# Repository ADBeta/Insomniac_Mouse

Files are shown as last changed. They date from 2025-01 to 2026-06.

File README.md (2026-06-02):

# Insomniac Mouse MkII
USB HID Mouse Device using a 10¢ Microcontroller.  
Moves randomly to keep PCs awake; make games harder to play; annoy co-workers 
and friends; or to give you a digital fishbowl to watch.  
Each board has jumpers to change the Mouse Behaviour, a lanyard loop,
and is designed with minimum cost and complexity.

Using [ch32v003fun](https://github.com/cnlohr/ch32v003fun) and 
[rv003usb](https://github.com/cnlohr/rv003usb) to create a Software Defined
HID Mouse - it then uses `Bresenham's Line Algorithm` to plot lines for the
mouse to move.

<div style="display: flex; align-items: center; gap: 10px;">
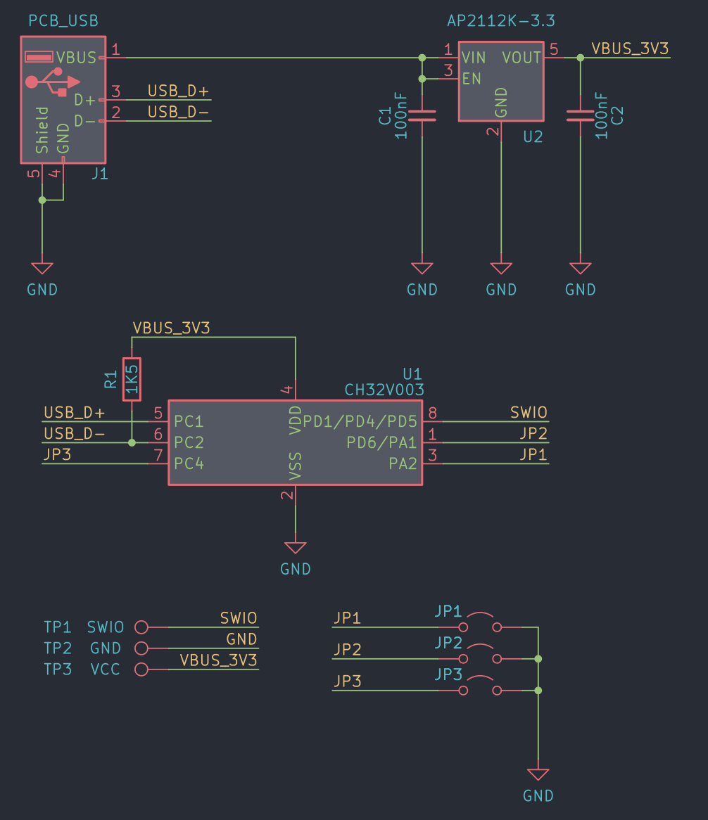
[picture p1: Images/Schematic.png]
Schematic
  <br>
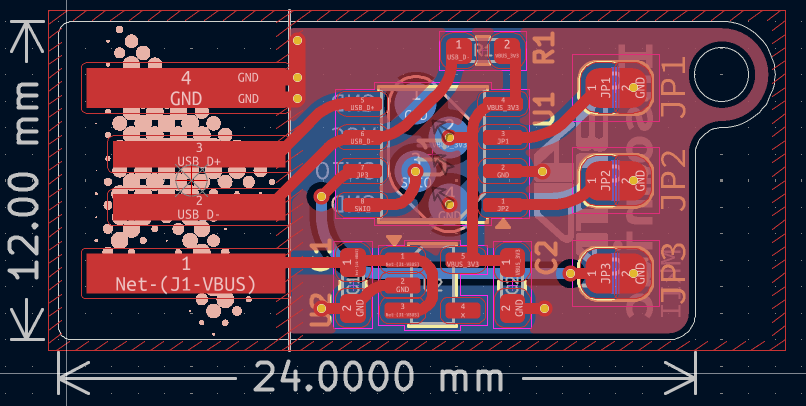
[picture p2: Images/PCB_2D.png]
PCB_2D
  <br>
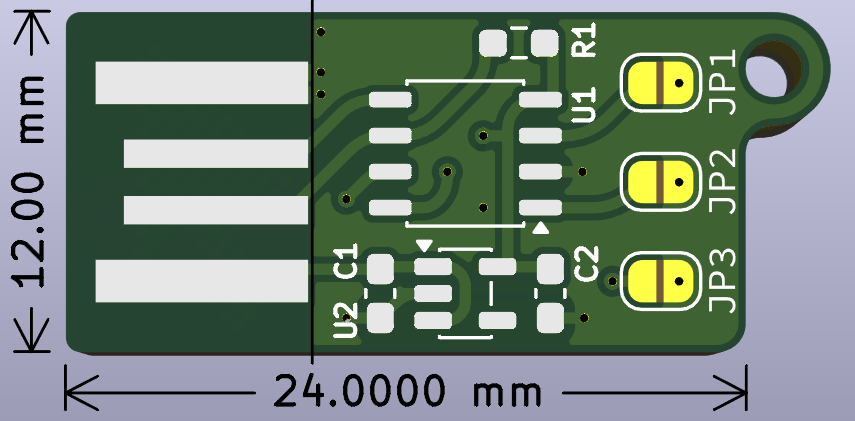
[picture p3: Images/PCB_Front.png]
PCB_Front
  
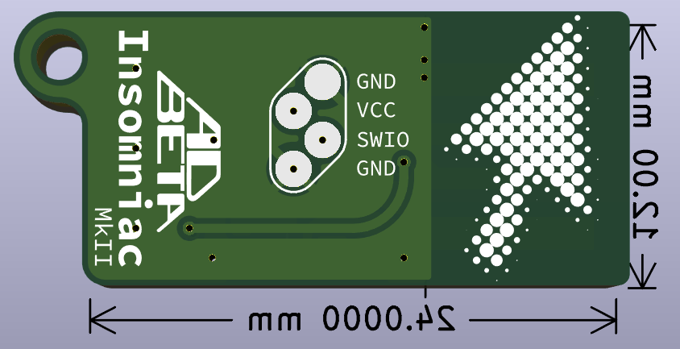
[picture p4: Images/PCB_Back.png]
PCB_Back
  
</div>

## Jumpers

| Mode | J1  | J2  | J3  | Description | Usecase |
|---|-----|-----|-----|---|---|
| Normal |  0  |  0  |  0  | ±125 Units Movement | Default balance of speed and distance |
| Hi-Res |  1  |  0  |  0  | ±250 Units Movement | Longer movement for Hi DPI Displays |
| Jitter |  0  |  1  |  0  | ±20 Units Movement | More chaotic movement. Good for messing with games |
| Stepped  |  1  |  1  |  0  | ±2 Unit Movement (Slower) | Slow mode for controllability while plugged in |
| Square |  0  |  0  |  1  | Lock movement to a square | Prevents the mouse from wandering too far |
| Unused |  1  |  0  |  1  | | |
| Unused |  0  |  1  |  1  | | |
| Unused |  1  |  1  |  1  | | |

## Uses
### Keeping PCs awake
Even if you disable Screensaver/Sleep mode, some PCs go to sleep anyway - 
this forces the machine to stay awake regardless.  
This is especially useful on Industial, Unmanaged and headless machines.

### Testing USB Ports
Due to the very low power consumption, small size, lanyard loop, USB 1.0
connection spec, and simple HID data, this is a perfect cheap USB Tester.

### Activity Monitor Spoofing
Because this moves the mouse like any other HID Mouse, it keeps users as
`"Online"` on Teams, Slack etc programs which monitor user activity.  
**WARNING This is not recommended, and any touble you get into for doing this
is your own fault.**

### Pranks / Game Challenges
Guaranteed to annoy your friends and make games **much** harder to play.  

### Creating Artwork
Hold down the mouse in an art package of your choice to create 
some.... interesting art.  
<div style="display: flex; align-items: center; gap: 10px;">
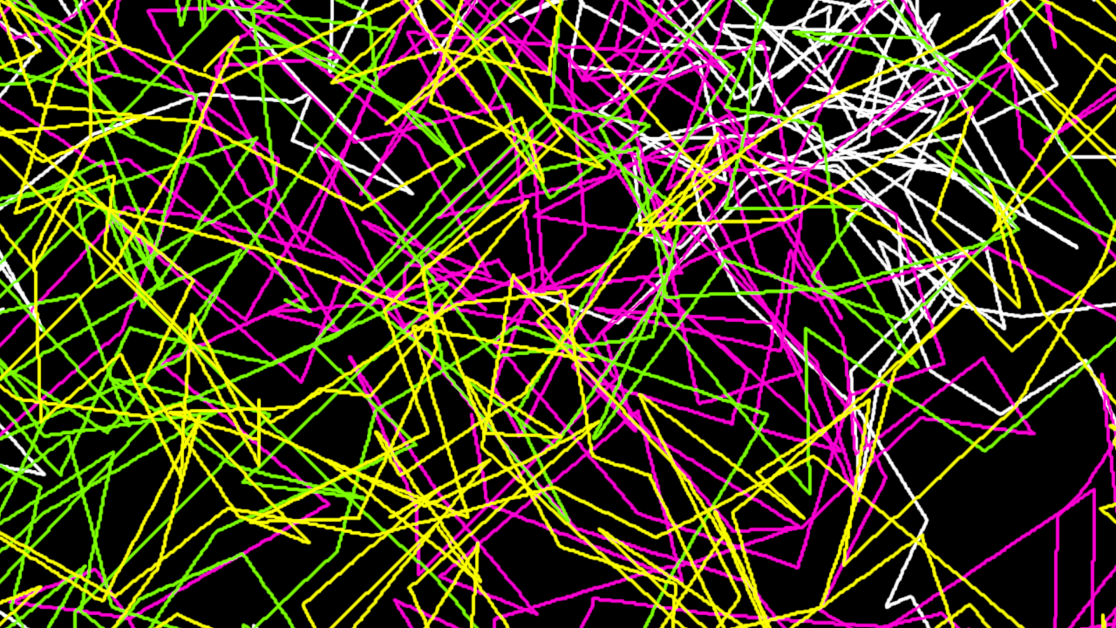
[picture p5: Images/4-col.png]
art 4 colour
  <br>
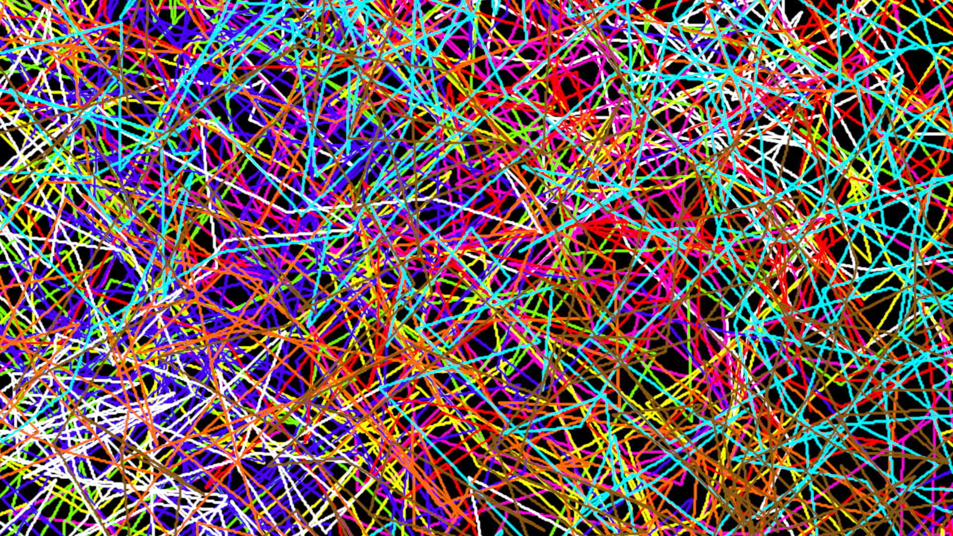
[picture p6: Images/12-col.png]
art 12 colour
  <br>
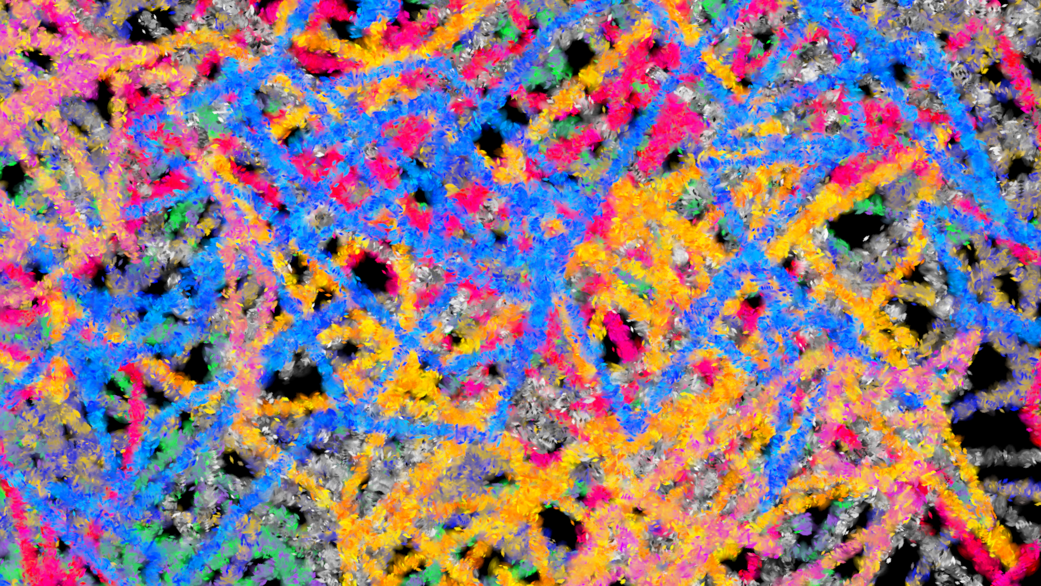
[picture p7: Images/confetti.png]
art confetti
  <br>
</div>

## PCB Specification
The overall thickness of the PCBs **MUST** be between 2.0mm and 2.4mm.  
`MkII` Offers more adaptability to get to this final thickness easily.
* Order `Insomniac_USB_Gerb` as a 2.0mm PCB
* Order `Insomniac_USB_Gerb` as a 1.6mm PCB and glue on a 0.4mm - 0.8mm Shim
* Order `Insomniac_USB_Gerb` and `Insomniac_Shim_Gerb` as 1.2mm or 1.0mm PCBs and glue together

## Partslist
```
U1    CH32V003J4M6       SOIC-8
U2    AP2112K-3.3        SOT-23-5
C1    100nF MLCC         0603
C2    100nF MLCC         0603
R1    1.5K Ohm           0603
```

## CHANGELOG
* V1.0.1 - Fixed a compatability issue with Windows
* V1.1.2 - Refactor functions and vairable names
* V1.2.0 - Added Diagonal Movement for USB HID Data, improves smoothness
* V1.3.2 - Changed Jumper Detection Method & added `JITTER` Mode
* V1.4.0 - Refined the code and added `CALM` Mode.
* V1.5.0 - Added USB Serial Number based on UUID of the MCU
* V2.0.0 - MkII PCB and minor bug fixes & refactor
* V2.1.0 - Added Square Limit Mode

## TODO

----
MIT License
Copyright (c) 2025-2026 ADBeta

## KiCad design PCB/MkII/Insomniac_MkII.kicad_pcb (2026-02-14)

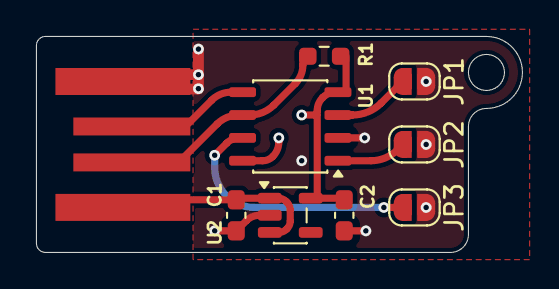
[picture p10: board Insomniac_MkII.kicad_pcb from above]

Board: 2 copper layers, 27.0 x 12.0 mm, 10 parts (1 on the bottom side), 9 nets.

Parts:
C1, C2: 100nF; C_0603_1608Metric_Pad1.08x0.95mm_HandSolder
J1: PCB_USB; PCB_USB_A
J2: CONN_PROG; Program_Conn
JP1: JP1; SolderJumper-2_P1.3mm_Open_RoundedPad1.0x1.5mm
JP2: JP2; SolderJumper-2_P1.3mm_Open_RoundedPad1.0x1.5mm
JP3: JP3; SolderJumper-2_P1.3mm_Open_RoundedPad1.0x1.5mm
R1: 1K5; R_0603_1608Metric_Pad0.98x0.95mm_HandSolder
U1: CH32V003JxMx; JEITA_SOIC-8_3.9x4.9mm_P1.27mm
U2: AP2112K-3.3; SOT-23-5

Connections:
/JP1: JP1.1 (A), U1.3 (PA2)
/JP2: JP2.1 (A), U1.1 (PD6/PA1)
/JP3: JP3.1 (A), U1.7 (PC4)
/SWIO: J2.3, U1.8 (PD1/PD4/PD5)
/USB_D+: J1.3 (D+), U1.5 (PC1)
/USB_D-: J1.2 (D-), R1.1, U1.6 (PC2)
/VBUS_3V3: C2.1, J2.2, R1.2, U1.4 (VDD), U2.5 (VOUT)
GND: C1.2, C2.2, J1.4 (GND), J2.1, J2.4, JP1.2 (B), JP2.2 (B), JP3.2 (B), U1.2 (VSS), U2.2 (GND)
unnamed: C1.1, J1.1 (VBUS), U2.1 (VIN), U2.3 (EN)

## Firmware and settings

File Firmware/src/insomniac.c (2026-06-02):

/******************************************************************************
* Insomiac Mouse Emulator
* Connects over USB as a generic HID Mouse, then moves continuously to keep
* PCs awake, or just to waste some time watching it dance!
* See the GitHub: https://github.com/ADBeta/Insomniac_Mouse
*
* Pinout:
* 	USB+   PC1
* 	USB-   PC2
* 	JP1    PA2
* 	JP2    PA1
* 	JP3    PC4
*
* ADBeta (c) 2025-2026    02 Jun 2026    Ver2.1.0
******************************************************************************/
#include "ch32v003fun.h"
#include "rv003usb.h"
#include "lib_rand.h"
#include "serial_uuid.h"

//#include <stdio.h>          // NOTE: Comment out when net debugging

/*** Macro Functions *********************************************************/
#define CLAMP(v, min, max)  ((v) < (min) ? (min) : ((v) > (max) ? (max) : (v)))


/*** Types and Definitions ***************************************************/
/// @brief A C-ordinate position struct, X/Y Data can be positive or negative
typedef struct {
	int16_t          x;
	int16_t          y;
} position_t;


/// @brief Remapping of a uint8_t to movement instruction, 2 nibbles
/// [Up    /   Down]  [Left  /  Right]
///  1100      0011    1100      0011
typedef uint8_t mouse_instr_t;
#define MOUSE_INSTR_U      0b11000000
#define MOUSE_INSTR_D      0b00110000
#define MOUSE_INSTR_L      0b00001100
#define MOUSE_INSTR_R      0b00000011


typedef enum {
	MI_BUFFER_OK             = 0,
	MI_BUFFER_NO_SPACE,             // No Space to append to buffer
	MI_BUFFER_NO_DATA               // No Data to read from the buffer
} mi_buffer_status_t;


// User Mode Selection from the Jumpers - Reads the jumpers in binary on boot
typedef enum {
	USER_MODE_NORMAL     = 0b000,
	USER_MODE_HI_RES     = 0b001,
	USER_MODE_JITTER     = 0b010,
	USER_MODE_STEPPED    = 0b011,
	USER_MODE_SQUARE     = 0b100
} user_mode_t;




/*** Globals *****************************************************************/
// Ring Buffer Variables
#define                 MI_BUFFER_SIZE   512
static mouse_instr_t    g_mi_buffer[MI_BUFFER_SIZE];
volatile uint32_t       g_mi_buffer_head = 0;
volatile uint32_t       g_mi_buffer_tail = 0;


// Buffer is ready for another movement flag.
// 0x00 Not Empty
// 0x01 Empty
volatile uint8_t        g_buffer_empty_flag = 0x00;


// User Settings Flags
static user_mode_t   g_user_mode     = USER_MODE_NORMAL;



/*** Forward Declarations ****************************************************/
/// @brief Efficient Implimentation of an integer abs() function
/// @param input x
/// @param output abs(x)
uint32_t int_abs(const int32_t x);


/// @brief Generates a random signed integer, limited to a maximum range
/// @param None
/// @return int16_t integer
int16_t int_rand(void);


/// @brief Mouse Instruction Ring Buffer Push (Puts data in the buffer)
/// @param Mouse Instruction
/// @return Mouse Instruction Status
mi_buffer_status_t mi_buffer_push(const mouse_instr_t inst);


/// @brief Mouse Instruction Ring Buffer Pop (Pulls off data from buffer)
/// @param Mouse Instruction Pointer
/// @return Mouse Instruction Status
mi_buffer_status_t mi_buffer_pop(mouse_instr_t *instr);


/// @brief Mouse Instruction Ring Buffer Peek (Reads value without incrimenting)
/// @param Mouse Instruction Pointer
/// @return Mouse Instruction Status
mi_buffer_status_t mi_buffer_peek(mouse_instr_t *instr);


/// @brief Mouse Instruction Ring Buffer Skip (Skip current buffer data)
/// @param None
/// @return Mouse Instruction Status
mi_buffer_status_t mi_buffer_skip(void);


/// @brief Plots movement to a given co-ordinate point. Appends the movement
/// data to the circuilar buffer to be dispatched to the USB Interrupt
/// @param postion_t endpoint to plot to. Contains X/Y data, can be positive
/// or negative
/// @return Mouse Inscription buffer status - if push fails
mi_buffer_status_t move_to_endpoint(const position_t endpoint);


/// @brief sets HID mouse bytes from an input Mouse Movement Instruction
/// @param buffer to modify
/// @param instruction to parse
/// @return None
void set_mouse_instr_bytes(uint8_t *buffer, mouse_instr_t instr);


/// @brief Tracks the absolute position of the pointer and limits it to a
/// given square
/// @param pos, pointer to the position to add, returns the modified position
/// @return None
void limit_endpoint_to_square(position_t *pos);



/*** Main ********************************************************************/
int main(void)
{
	/*** System Init ********************/
	// Grab two words from the near-top of RAM - Should be uninitialised noise
	uint32_t ram_val =   *((volatile uint32_t*)0x20000700) 
		               ^ *((volatile uint32_t*)0x200007AA);
	// Set the LFSR Seed to the RAM Value, provided it is not 0x00.. or 0xFF..
	// If this doesn't seed the default will be used
	if(ram_val != 0x00000000 && ram_val != 0xFFFFFFFF)
		seed(ram_val);


	SystemInit();


	// Set the USB Serial String to the UUID of the MCU
	set_usb_serial_uuid();


	/*** GPIO ***************************/
	// Enable the GPIO Channels
	RCC->APB2PCENR |= RCC_APB2Periph_GPIOA | RCC_APB2Periph_GPIOC;

	// Clear PA1 PA2 and PC4, set them to Push/Pull, then write PULLUP
	GPIOA->CFGLR &= ~((0x0000000F << 4) | (0x0000000F << 8));
	GPIOA->CFGLR |=  ((GPIO_CFGLR_IN_PUPD << 4) | (GPIO_CFGLR_IN_PUPD << 8));
	GPIOA->OUTDR |=  ((0x01 << 1) | (0x01 << 2));

	GPIOC->CFGLR &= ~(0x0000000F << 16);
	GPIOC->CFGLR |=  (GPIO_CFGLR_IN_PUPD << 16);
	GPIOC->OUTDR |=  (0x01 << 4);

	// Read the Jumpers to set the user_mode
	g_user_mode |= (!((GPIOA->INDR >> 2) & 1)) << 0;  // PA2
	g_user_mode |= (!((GPIOA->INDR >> 1) & 1)) << 1;  // PA1
	g_user_mode |= (!((GPIOC->INDR >> 4) & 1)) << 2;  // PC4


	/*** USB ****************************/
	// Ensures USB re-enumeration after bootloader or reset
	Delay_Ms(1); 
	usb_setup();


	while(1) 
	{
		// NOTE: Prints random values to evaluate random number algorithm
		//printf("%d\n", int_rand());

		// Wait for the flag that the buffer is empty
		if(g_buffer_empty_flag)
		{
			// Generate a random position then push the commands to move to it
			position_t rand_pos = {.x = int_rand(), .y = int_rand()};

			// Limit the Endpoints to a defined square if selected
			if(g_user_mode == USER_MODE_SQUARE)
				limit_endpoint_to_square(&rand_pos);
			
			// Move to the given endpoint
			move_to_endpoint(rand_pos);

			// Reset the empty flag, waits until it is done moving
			g_buffer_empty_flag = 0x00;			
		}


		// Add a delay for Calm mode to increase usability
		if(g_user_mode == USER_MODE_STEPPED)
			Delay_Ms(1000);

	} 
	// end of loop
	

	return 0;
}



/*** Functions ***************************************************************/
// rv003usb HID Function
void usb_handle_user_in_request( struct usb_endpoint * e, uint8_t * scratchpad, int endp, uint32_t sendtok, struct rv003usb_internal * ist )
{
	static mouse_instr_t crnt_mouse_instr;
	static mouse_instr_t next_mouse_instr;
	// Define an empty mouse bytes array
	uint8_t mouse_bytes[4] = {0x00, 0x00, 0x00, 0x00};

	// Handle the USB Mouse messages
	if(endp == 1)
	{
		// Get the current and next data chunks
		mi_buffer_status_t crnt_buffer_status = mi_buffer_pop(&crnt_mouse_instr);
		mi_buffer_status_t next_buffer_status = mi_buffer_peek(&next_mouse_instr);

		// If the current status is OK, set the data bytes
		if(crnt_buffer_status == MI_BUFFER_OK)
		{
			set_mouse_instr_bytes(mouse_bytes, crnt_mouse_instr);
		}

		// If it's empty, set the flag and leave the buffer unset
		else
		{
			g_buffer_empty_flag = 0x01;
		}


		// If the next instruction is valid, parse it (Allows for diagonal movement)
		if(next_buffer_status == MI_BUFFER_OK)
		{
			// If this instruction is LEFT or RIGHT, and the previous was UP or DOWN,
			// add this instruction to the data
			if((next_mouse_instr == MOUSE_INSTR_L || next_mouse_instr == MOUSE_INSTR_R)
			&& (crnt_mouse_instr == MOUSE_INSTR_U || crnt_mouse_instr == MOUSE_INSTR_D))
			{
				set_mouse_instr_bytes(mouse_bytes, next_mouse_instr);
				mi_buffer_skip();
			}

			// Likewise with UP and DOWN, append if last instruction was LEFT or RIGHT
			if((next_mouse_instr == MOUSE_INSTR_U || next_mouse_instr == MOUSE_INSTR_D)
			&& (crnt_mouse_instr == MOUSE_INSTR_L || crnt_mouse_instr == MOUSE_INSTR_R))
			{
				set_mouse_instr_bytes(mouse_bytes, next_mouse_instr);
				mi_buffer_skip();
			}
		}
		

		// Send the data to the USB Controller - Either 0x00's or has Delta data
		usb_send_data(mouse_bytes, 4, 0, sendtok);
	}
	else
	{
		// If it's a control transfer, empty it.
		usb_send_empty(sendtok);
	}
}


void set_mouse_instr_bytes(uint8_t buffer[], mouse_instr_t instr)
{
	// signed 8 bit ints for movement, using Unsigned representation
	// [1] is (0xFF)L  (0x01)R
	// [2] is (0xFF)U  (0x01)D
	switch(instr)
	{
		case MOUSE_INSTR_L:
			buffer[1] |= 0xFF;
			break;
		case MOUSE_INSTR_R:
			buffer[1] |= 0x01;
			break;

		case MOUSE_INSTR_U:
			buffer[2] |= 0xFF;
			break;
		case MOUSE_INSTR_D:
			buffer[2] |= 0x01;
			break;
	}
}


int16_t int_rand(void)
{
	int16_t rand_num;

	// NOTE: Generate a random number, bitmask it to get it within range
	// so the modulo operation isn't noticable slow.
	// Modulo by (Maximum + 1), then subtract (Maximum / 2)

	// Generate different Ranges based on user setup
	switch(g_user_mode)
	{
		// +- 125 Units
		case USER_MODE_NORMAL:
		case USER_MODE_SQUARE:
			rand_num = rand() & 0x01FF; 
			rand_num = (rand_num % 251) - 125;
			break;
		

		// +- 250 Units
		case USER_MODE_HI_RES:
			rand_num = rand() & 0x03FF;
			rand_num = (rand_num % 501) - 250;
			break;


		// +- 20 Units
		case USER_MODE_JITTER:
			rand_num = rand() & 0x007F; 
			rand_num = (rand_num % 41) - 20;
			break;


		// +- 2 Unit
		case USER_MODE_STEPPED:
			rand_num = rand() & 0x000F;
			rand_num = (rand_num % 5) - 2;
			break;


		default:
			rand_num = 0x00;
			break;
	}

    return rand_num;
}


uint32_t int_abs(const int32_t x)
{
	// Extract the sign bit
	uint32_t mask = x >> 31;
	// Invert the 2's compliment
	return (x ^ mask) - mask;
}


mi_buffer_status_t mi_buffer_push(const mouse_instr_t instr)
{
	// Calculate the next head position
	uint32_t next_head = (g_mi_buffer_head + 1) % MI_BUFFER_SIZE;
	// If there is no space left in the buffer, reject incomming data
	if(next_head == g_mi_buffer_tail) return MI_BUFFER_NO_SPACE;

	// Append the data to the current head position
	g_mi_buffer[g_mi_buffer_head] = instr;
	// Update the current head position
	g_mi_buffer_head = next_head;

	return MI_BUFFER_OK;
}


mi_buffer_status_t mi_buffer_pop(mouse_instr_t *instr)
{
	// Exit if there is no more data to be popped off
	if(g_mi_buffer_head == g_mi_buffer_tail) return MI_BUFFER_NO_DATA;
	// Set the data pointer from the buffer
	*instr = g_mi_buffer[g_mi_buffer_tail];

	// Update the Tail Position
	g_mi_buffer_tail = (g_mi_buffer_tail + 1) % MI_BUFFER_SIZE;

	return MI_BUFFER_OK;
}


mi_buffer_status_t mi_buffer_peek(mouse_instr_t *instr)
{
	// Exit if there is no more data to be popped off
	if(g_mi_buffer_head == g_mi_buffer_tail) return MI_BUFFER_NO_DATA;
	// Set the data pointer from the buffer
	*instr = g_mi_buffer[g_mi_buffer_tail];

	return MI_BUFFER_OK;
}


mi_buffer_status_t mi_buffer_skip(void)
{
	// Update the Tail Position
	g_mi_buffer_tail = (g_mi_buffer_tail + 1) % MI_BUFFER_SIZE;
	return MI_BUFFER_OK;
}


mi_buffer_status_t move_to_endpoint(const position_t endpoint)
{
	mi_buffer_status_t mi_return = MI_BUFFER_OK;
 
	position_t startpoint = {0, 0};

	// Bresenham variables
	// Delta x and y - total distances to cover in x and y direction
	int32_t x_delta = int_abs(endpoint.x - startpoint.x);
	int32_t y_delta = int_abs(endpoint.y - startpoint.y);
	// Which direction to step in
	int32_t x_step = (startpoint.x < endpoint.x)  ?  1 : -1;
	int32_t y_step = (startpoint.y < endpoint.y)  ?  1 : -1;
	// Accumulated Error - how far from the ideal line we are
	int32_t err = x_delta - y_delta;


	// Step through the line until the destination is reached
	while(startpoint.x != endpoint.x || startpoint.y != endpoint.y) 
	{
		// Multiply the error by 2 to avoid fractional calculations
		int32_t err2 = err * 2;

		// Step in the X direction - remove vertical error to account for
		// the change in horizontal position
		if(err2 > -y_delta)
		{
			err -= y_delta;
			startpoint.x += x_step;

			// Push Left or Right instructions to the Mouse Delta Buffer
			mi_return = mi_buffer_push( (x_step > 0) ? MOUSE_INSTR_R : MOUSE_INSTR_L);
			// If the buffer is full, exit early
			if(mi_return != MI_BUFFER_OK)  return mi_return;
		}

		// Step in the Y direction - add the horizontal error to account for
		// the change in vertical position
		if(err2 < x_delta) 
		{
			err += x_delta;
			startpoint.y += y_step;

			// Push Up and Down Instructions to the Mouse Delta Buffer
			mi_return = mi_buffer_push( (y_step > 0) ? MOUSE_INSTR_U : MOUSE_INSTR_D);
			// If the buffer is full, exit early
			if(mi_return != MI_BUFFER_OK)  return mi_return;
		}
	}

	return mi_return;
}


void limit_endpoint_to_square(position_t *pos)
{
	#define POS_X_MAX   50
	#define POS_Y_MAX   50
	static position_t absolute_pos = {0, 0};

	// Copy the absolute position to get a delta
	position_t old_pos = absolute_pos;

	// Add the current posisiton delta to the absolute position
	absolute_pos.x += pos->x;
	absolute_pos.y += pos->y;

	// Clamp to the bounds of the square
	absolute_pos.x = CLAMP(absolute_pos.x, -POS_X_MAX, POS_X_MAX);
	absolute_pos.y = CLAMP(absolute_pos.y, -POS_Y_MAX, POS_Y_MAX);
	
	// Return the actual movement that was allowed
	pos->x = absolute_pos.x - old_pos.x;
	pos->y = absolute_pos.y - old_pos.y;
}

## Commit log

2025-01-12 PCB Finished
    [Insomniac.kicad_pcb, Insomniac.kicad_sch, log.csv]
2025-01-18 Added peek and skip buffer functions for use later
    [insomniac.c]
2025-01-20 Added Images
    [Insomniac.kicad_pcb]
2025-02-21 Changed Serial No. to 8 char. Testing Multi-device support
2026-02-14 MkII HW & FW
    [Insomniac.kicad_pcb, Insomniac.kicad_sch, Insomniac_MkII.kicad_pcb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]
